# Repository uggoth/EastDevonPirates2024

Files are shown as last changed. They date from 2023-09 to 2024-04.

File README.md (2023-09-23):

# EastDevonPirates2024
Work towards Pi Wars 2024 by East Devon Pirates
Collaborating on ZyderBot, our autonomous robot entry for PiWars2024 (theme Disaster Zone)

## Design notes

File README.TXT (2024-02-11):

ZyderBot 11

Pi:   BENJI
Pico: R

Working directory is ColinThisPi
Copy new stuff into ColinBENJI then git push

startup.sh runs main program

-------------- integration ------------------------

lsusb
pico shows up as:  MicroPython Board in FS mode
ESP32 shows up as: QinHeng Electronics CH340 serial converter

ls /dev/tty*
pico shows up as:   /dev/tty/ACM0
ESP32 shows up as:  /dev/tty/USB0 (or possibly USB1)

Use Thonny on Pi for Pico. Works perfectly
Use Arduino 1.8.19 on Pi for ESP32. Compile fails, but serial monitor works
Use Arduino 2.3.0 on PC. Works perfectly (but not available for AMD architecture)

-------------- handshake test ---------------------

handshake pin on Pi is declared:
    pin_no = 18
    gpio.set_mode(pin_no, pigpio.INPUT)
    gpio.set_pull_up_down(pin_no, pigpio.PUD_UP)

handshake pin on ESP32 is declared:
    const int HANDSHAKE_PIN = 12;
    pinMode(HANDSHAKE_PIN, OUTPUT);

ESP32 sets handshake pin HIGH to signal ready to receive a command
sets LOW to indicate busy

Pi reads high pin as 1
low pi as 0
waits for 1 for 1 second, then gives up

Run  /home/pi/EastDevonPirates2024/ESP32CAMCode/HandshakeTestA/HandshakeTestA.ino on the ESP32
Run  /home/pi/ColinPiTests/test_15_A_handshake_esp32.py on the Pi
(Note: ColinPiTests is a GitHub repository to facilitate transfers)

-------------- command stream testing -------------

Run  main_test_command_stream_B_v02.py  on the Pico
Run  /home/pi/ColinThisPi/main_double_test_v01.py  on the Pi
Run  /home/pi/EastDevonPirates2024/ESP32CAMCode/CommandProtocolTestA/CommandProtocolTestA.ino on the ESP32
(Note: EastDevonPirates2024 is a GitHub repository to facilitate transfers)
Turns headlights on and off with Pico
Would turn flashlight on and off on ESP32 if it worked

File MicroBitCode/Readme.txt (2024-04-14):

Instructions for compiling to run on a Microbit.

Please note that the modulus notation for the direction needle will not 
compile on Mu Editor 1.2 on MacOS, but fine on the online python.MicroBit.org 
site and on Thonny 4.1.3 as at 20240410

compass-with-turn-indication-main.py 

Calibrates the compass by twisting in 3-axes until all the display LEDs are lit, 
then after a few seconds delay, gives a smiley on the LEDs, with a 115200 8-n-1 
output of degrees from north to the usb port, whilst using the accelerometer to 
Indicate a right or left turn on the LEDs.

Compass-needle-main.py
 
Is an extension to the above, replacing the accelerometer output with a bar 
Indicator on the LED’s pointing to North. this is a direct copy from the API documents.
 
WARNING does not compile on MU Editor v1.2 as it fails to recognise modulus symbol!

Compass-needle.hex is test code

Compass-needle-2.hex is the operational hex file to be copied to the MicroBit’s 
internal folder.

Paula Taylor East Devon Pirates 20240411

added
 
Accelerometer-only-v1-main.py

Accelerometer-only-v1.hex

Gives indication of change in direction to LEDS and printed output to serial port, no calibration needed as all output is movement relative.

Paula 20240414

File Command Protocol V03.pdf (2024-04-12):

# Command Protocol V03

We use intelligent aachments, with controllers made from Raspberry Picos, ESP32s, Arduinos etc. and communicate from the central Raspberry Pi via a serial link over USB using a command protocol. The version of this used in 2022 was very compact, but lacking in some facilies, so I have added a bit more to it, but as lile as possible.

All communicaon is iniated by the Pi. The controller cannot iniate anything. In normal use clashes are unlikely. However, to prevent clashes when the computers are busy, there is a handshake. For Pi to Pico this is a GPIO to GPIO wire. At the Pico end it is an output GPIO declared as:
machine.Pin(pin_no, machine.Pin.OUT)
At the Pi end it is an input GPIO declared as:
pigpio.set_mode(pin_no, pigpio.INPUT) pigpio.set_pull_up_down(pin_no, pigpio.PUD_UP)
If the Pico has done nothing, or the wire is disconnected, the Pi value is 1 (not 0) because of the pullup, therefore a value of 1 indicates that it is set off. Because this can be confusing the Pico has funcons set_on() and set_off(), while the Pi has is_on() which returns True or False. The controller sets the handshake to say it is ready to receive one command and unsets it while busy acng on the command. The Pi only sends commands when the Pico is ready.
The Pi has funcons:
send_command() waits a certain length of me for the handshake, if med out returns with a status code, otherwise it sends the command and waits for the feedback, which the Pico sends instantly, and then returns while the command is executed.
send_command_and_wait() is the same up to the end, where it waits aer feedback for the handshake to be set again

All communicaon is via printable characters. The command format is:
serial_no - a four character string, which gets reflected back to the Pi so the Pi can detect drop-outs if it wants to.
command - a four character command. Command sets vary according to the applicaon, but always include:
WHOU - a request for the controller to idenfy itself, in case there are mulple controllers
EXIT - an instrucon to close down
data - this is oponal and obviously applicaon dependent. If numeric it should consist of 4 digit items to be interpreted as integers.
example: 0001DRIV0050000001000000 is
serial no: 1
command: DRIV
steering: 50
throle: 0
duraon: 100 (milliseconds)
crab: 0

The controller responds immediately to every command by echoing the serial number, followed by OKOK if all is well, or some error message.
example: 0001BADCCommand not understood
Note that OKOK does not mean that the command can be executed, just that it is received and understood.

There are objects for the Pi (in ColinPiClasses) and the Pico (in ColinPicoClasses). Typical usage on the Pi would be (N.B. code not tested; it’s just a hint):
import pigpio
gpio = pigpio.pi()
import CommandStream_V05 as CommandStream
handshake = CommandStream.Handshake(4, gpio)
pico_id = 'PICOA'
my_pico = CommandStream.Pico(pico_id, gpio, handshake) serial_no_sent = 0
serial_no_sent_string = '{:04f}'.format(serial_no_sent) command = 'WHOU’
serial_no_returned, feedback, data = my_pico.send_command( serial_no_sent_string + command)
if serial_no_returned != serial_no_sent_string:
raise (ColError(’sequence error’))
serial_no_sent += 1

Typical Pico usage:
import CommandStreamPico_V05 as CommandStream
my_handshake = ThisPico.ThisHandshake()
my_stream = CommandStream.CommandStream('From Pi', my_handshake) serial_no, command, data = my_stream.get()
if command == 'WHOU':
my_stream.send(serial_no + 'OKOK' + 'PICOA')

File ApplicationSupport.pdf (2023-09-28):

# East Devon PIrates - Pi Wars 2024

The basis for our 2024 entry is the 2022 entry. This has already been tidied up with more wiring underneath, so the top is less cluttered, though you might not think so from this picture! The basic structure, with an articulated attachment platform worked well, so we are keeping it.

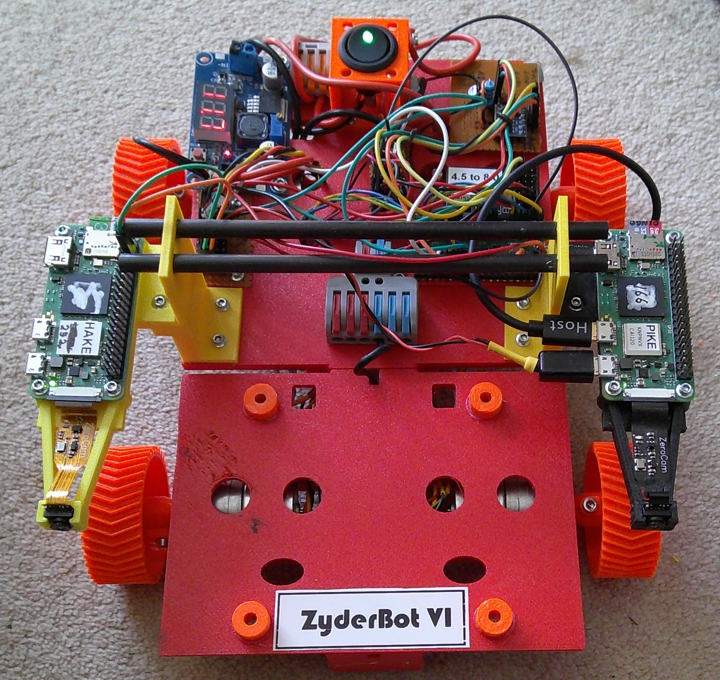
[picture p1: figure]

The robot can be remote controlled with just the Pico, so the Pi Zeros can be removed if not required (they are rather vulnerable to knocks)

The stereo Pi Zeros actually worked to some extent for the 2022 challenge, but the level of accuracy we asked of them was unobtainable. For 2024 we are just doing object identification (including line following) which is a lot simpler than SLAM, so we expect good results.

As an example of our approach, we have started work on object identification, and have created a utility for visualising colours in HSV (we are more used to RGB). This lets you play around with the OpenCV parameters in real time. In the picture I am trying to select the red crab against a complex background, with some success. Incidentally, this involves running OpenCV under the control of TKinter on a Pi Zero! You never know what’s possible until you try.

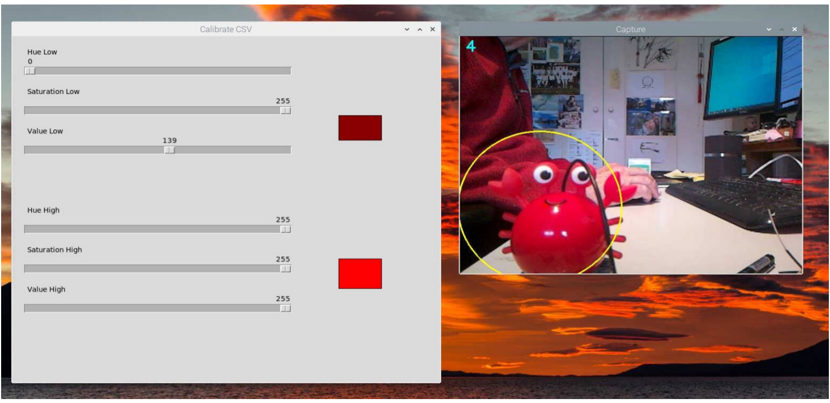
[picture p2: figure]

We have given robot demonstrations to local schools and groups (e.g. Scouts), which went down well, but have not managed to get them interested in following our Pi Wars journey. We will try again this year, and could mentor a local group if any kids nearby have entered.

We hope to have a busy and productive winter, and see you all in Cambridge

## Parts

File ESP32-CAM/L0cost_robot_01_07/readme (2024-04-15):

Consolidated version for PiWars submission

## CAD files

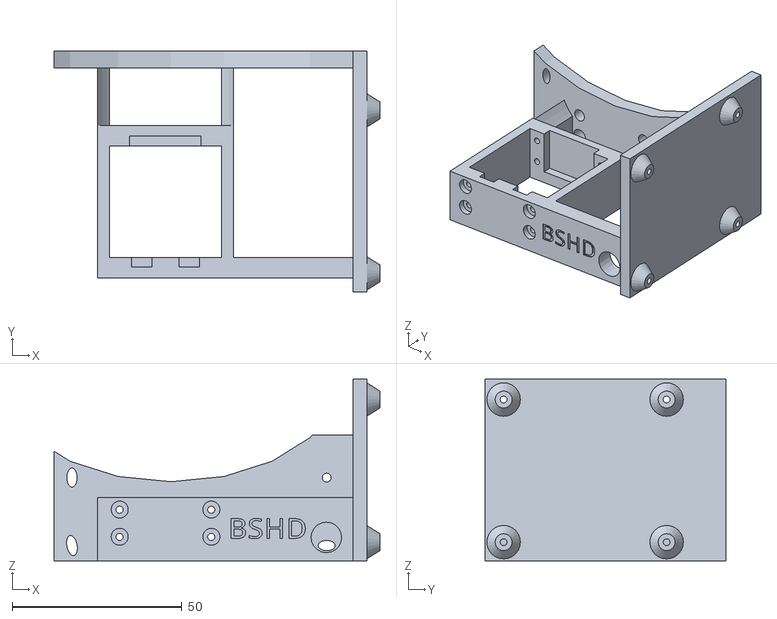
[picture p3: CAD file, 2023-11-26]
STL/ZZA Base Servo Holder D.stl
96.0 x 71.0 x 53.5

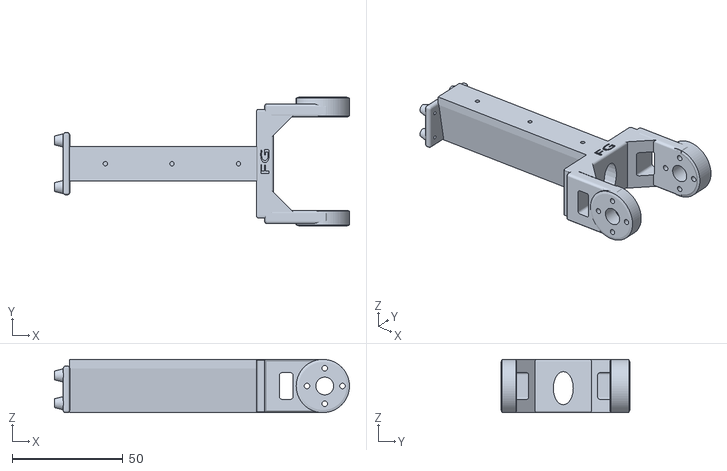
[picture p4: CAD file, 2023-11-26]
STL/ZZA Femur G.stl
132.9 x 58.0 x 24.0

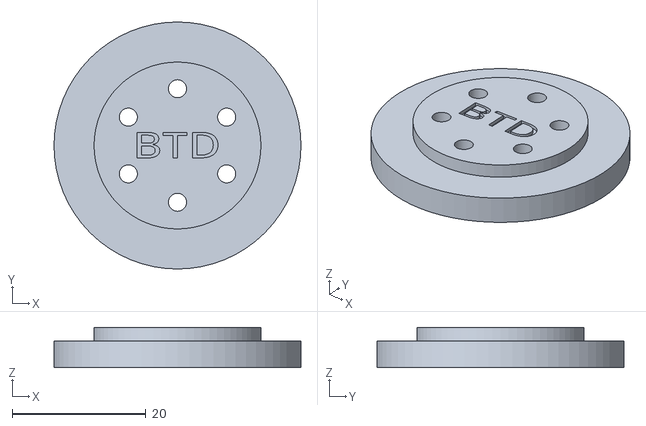
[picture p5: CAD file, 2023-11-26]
STL/ZZA Bearing Top D.stl
37.0 x 37.0 x 6.00

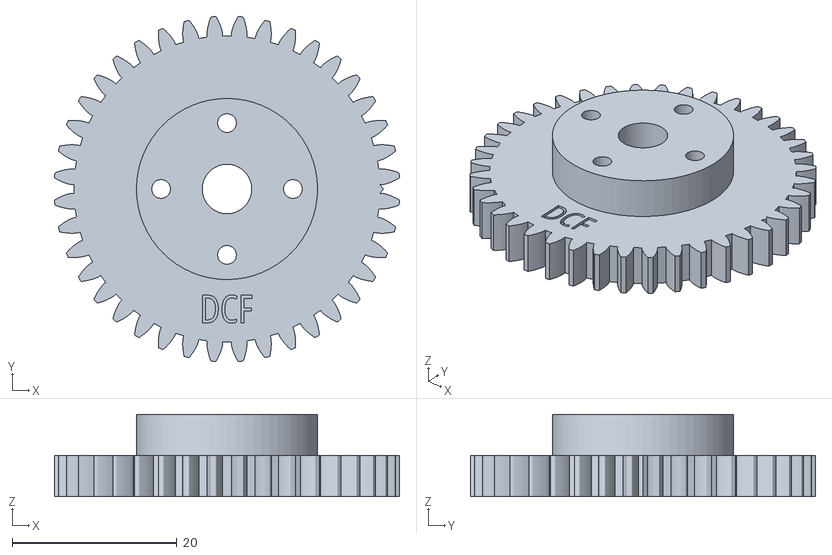
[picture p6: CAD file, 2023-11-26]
STL/ZZA Drive Cogwheel F.stl
41.9 x 41.9 x 10.0

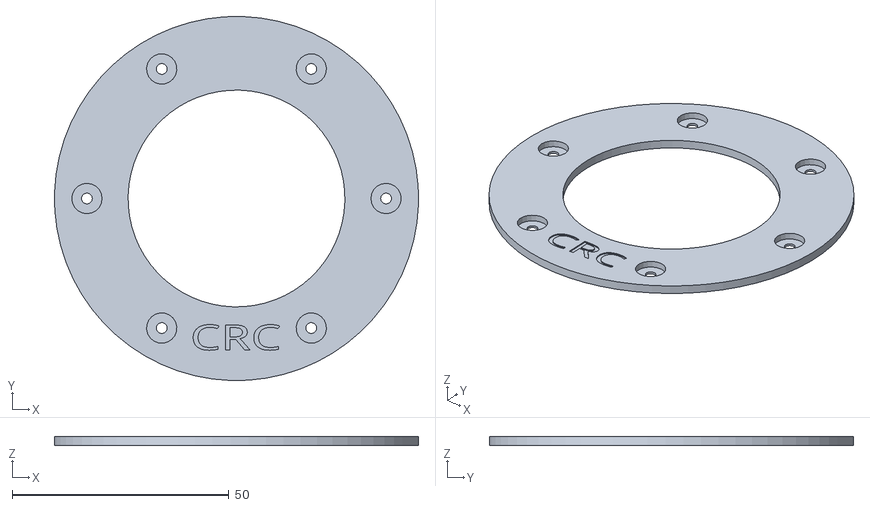
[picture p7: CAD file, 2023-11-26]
STL/ZZA Clamp Ring C.stl
84.0 x 84.0 x 2.00

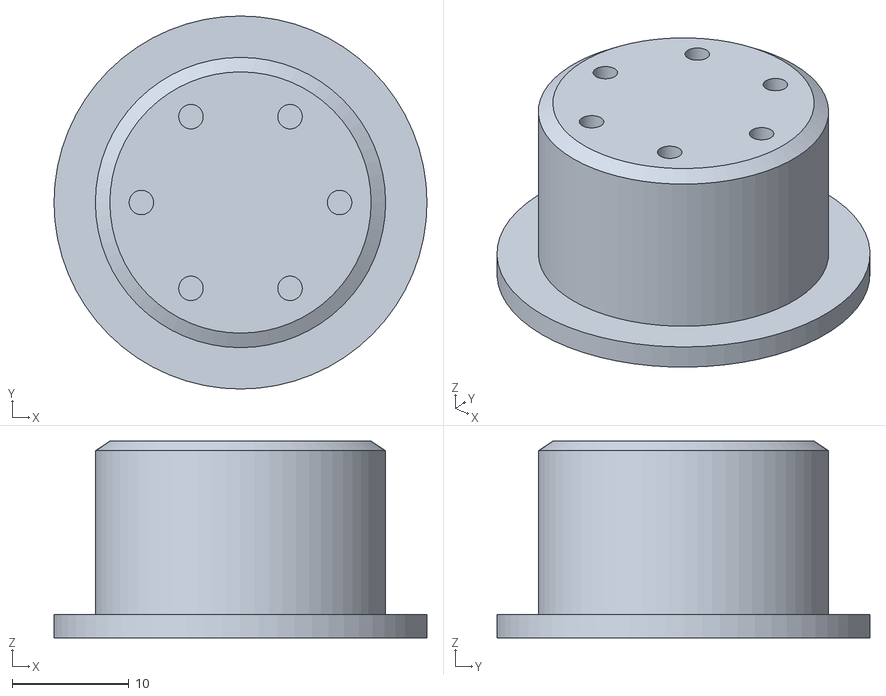
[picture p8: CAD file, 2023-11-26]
STL/ZZA Bearing Prong A.stl
32.0 x 32.0 x 16.9

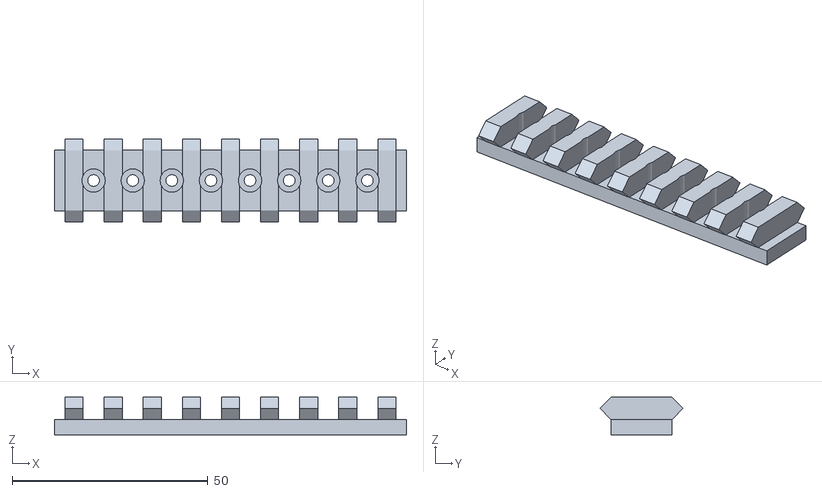
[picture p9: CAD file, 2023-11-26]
STL/ZZA Picatinny Rail C.stl
90.0 x 21.2 x 9.70

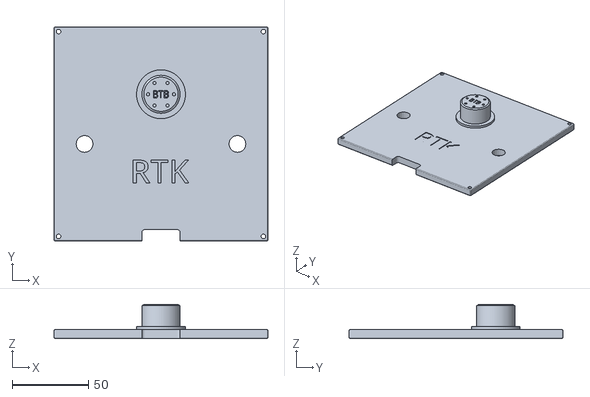
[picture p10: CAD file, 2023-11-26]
STL/ZZA Rear Top K.stl
140.0 x 140.0 x 22.3

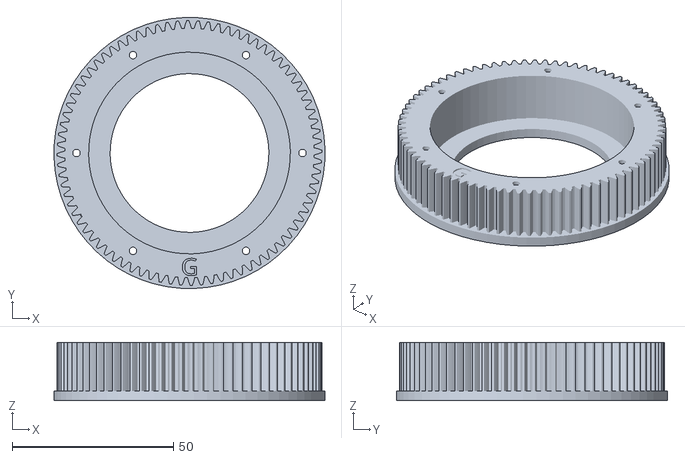
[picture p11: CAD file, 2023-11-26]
STL/ZZA Bearing Gear G.stl
84.0 x 84.0 x 18.0

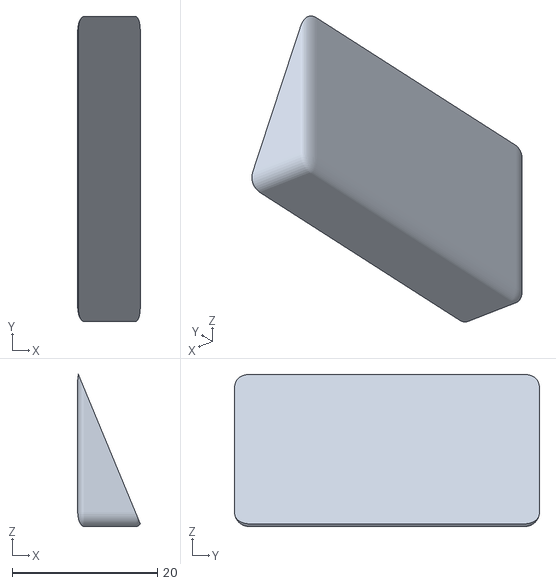
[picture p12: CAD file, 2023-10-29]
STL/ZyderBot 8 Side Window A.stl
8.62 x 42.0 x 20.9

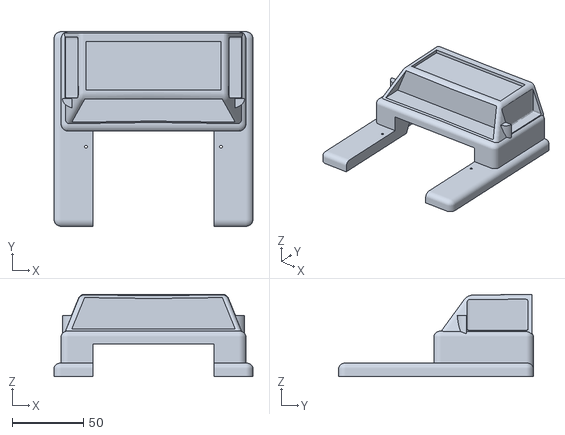
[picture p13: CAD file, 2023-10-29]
STL/ZyderBot 8 Cab G.stl
140.0 x 137.0 x 57.9

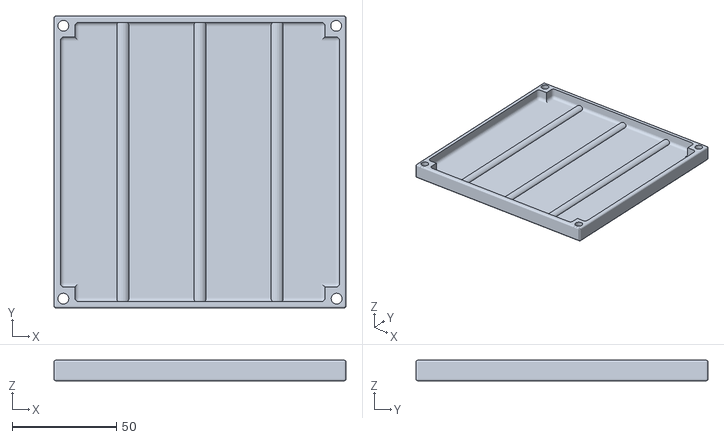
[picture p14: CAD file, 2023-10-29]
STL/ZyderBot 8 Chassis RL.stl
140.0 x 140.0 x 10.0

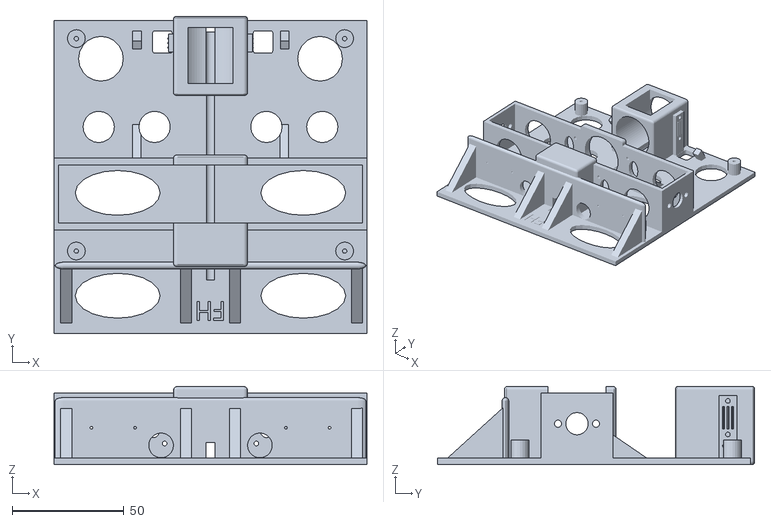
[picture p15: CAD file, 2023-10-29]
STL/ZyderBot 8 Chassis FH.stl
140.0 x 142.0 x 35.0

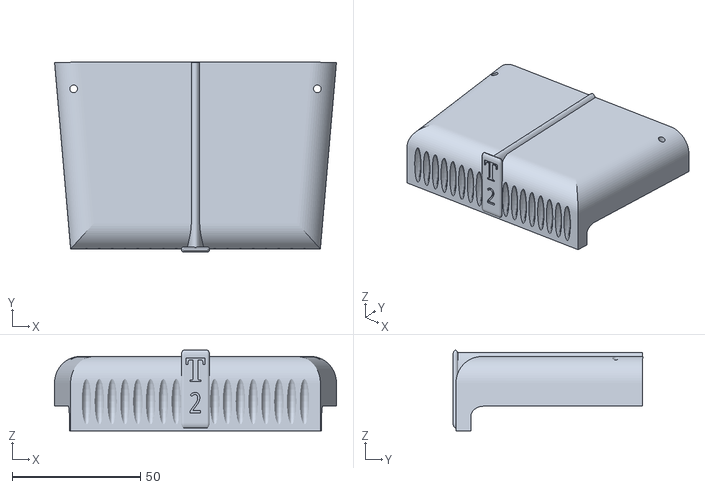
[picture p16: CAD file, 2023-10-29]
STL/ZyderBot 8 Bonnet A.stl
110.0 x 74.1 x 31.5

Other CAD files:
STL/ZyderBot 8 Front Window B.stl
STL/ZyderBot 8 Chassis RTD.stl

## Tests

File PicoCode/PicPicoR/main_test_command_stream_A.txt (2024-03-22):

Received: 0000WHOU

Sending: 0000PICOR
Received: 0001WHOU

Sending: 0001PICOR
Received: 0002HREV

Sending: 0002OKOK
Received: 0003Garbage

Sending: 0003BADC
Received: 0004HFWD

Sending: 0004OKOK
Received: 0005Garbij

Sending: 0005BADC
Received: 0006HOFF

Sending: 0006OKOK
Received: 0007EXIT

Sending: 0007OKOK
Exiting

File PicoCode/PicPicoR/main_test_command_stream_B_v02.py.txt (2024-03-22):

main_test_command_stream_B_v02.py starting

Received: 0000WHOU

Sending: 0000OKOKPICOR
Received: 0001WHOU

Sending: 0001OKOKPICOR
Received: 0006HFWD

Sending: 0006OKOK
Received: 0007HOFF

Sending: 0007OKOK
Received: 0008STOP

Sending: 0008OKOK
Received: 0000WHOU

Sending: 0000OKOKPICOR
Received: 0001WHOU

Sending: 0001OKOKPICOR
Received: 0006HFWD

Sending: 0006OKOK
Received: 0007HOFF

Sending: 0007OKOK
Received: 0008STOP

Sending: 0008OKOK
Received: 0000WHOU

Sending: 0000OKOKPICOR
Received: 0001WHOU

Sending: 0001OKOKPICOR
Received: 0006HFWD

Sending: 0006OKOK
Received: 0007HOFF

Sending: 0007OKOK
Received: 0008STOP

Sending: 0008OKOK
Received: 0000WHOU

Sending: 0000OKOKPICOR
Received: 0001WHOU

Sending: 0001OKOKPICOR
Received: 0006HFWD

Sending: 0006OKOK
Received: 0007HOFF

Sending: 0007OKOK
Received: 0008STOP

Sending: 0008OKOK
Received: 0000WHOU

Sending: 0000OKOKPICOR
Received: 0001WHOU

Sending: 0001OKOKPICOR
Received: 0006HFWD

Sending: 0006OKOK
Received: 0007HOFF

Sending: 0007OKOK
Received: 0008STOP

Sending: 0008OKOK
Received: 0000WHOU

Sending: 0000OKOKPICOR
Received: 0001WHOU

Sending: 0001OKOKPICOR
Received: 0006HFWD

Sending: 0006OKOK
Received: 0007HOFF

Sending: 0007OKOK
Received: 0008STOP

Sending: 0008OKOK
Received: 0000WHOU

Sending: 0000OKOKPICOR
Received: 0001WHOU

Sending: 0001OKOKPICOR
Received: 0006HFWD

Sending: 0006OKOK
Received: 0007HOFF

Sending: 0007OKOK
Received: 0008STOP

Sending: 0008OKOK

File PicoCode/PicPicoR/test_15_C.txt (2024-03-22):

LOOP 0
LOOP 1
LOOP 2
LOOP 3
LOOP 4
LOOP 5
LOOP 6
LOOP 7
LOOP 8

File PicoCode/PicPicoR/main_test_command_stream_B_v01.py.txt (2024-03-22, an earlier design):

main_test_command_stream_B_v01.py starting

Received: 0000WHOU

Sending: 0000PICOR
Received: 0001HREV

Sending: 0001OKOK
Received: 0002HFWD

Sending: 0002OKOK
Received: 0003HOFF

Sending: 0003OKOK
Received: 0004DRIV00500000000

Sending: 0004OKOK
spin: 0, fore_and_aft: 50, crab: 0mix a

mix b

running a
running a
running b
Received: 0005DRIV000000000000

Sending: 0005OKOK
spin: 0, fore_and_aft: 0, crab: 0mix a

running a
running a
running b
Received: 0006HOFF

Sending: 0006OKOK
Received: 0000WHOU

Sending: 0000PICOR
Received: 0001HREV

Sending: 0001OKOK
Received: 0002HFWD

Sending: 0002OKOK
Received: 0003HOFF

Sending: 0003OKOK
Received: 0004DRIV00500000000z

Sending: 0004BADC
Received: 0005DRIV000000000000

Sending: 0005OKOK
spin: 0, fore_and_aft: 0, crab: 0mix a

running a
running a
running b
Received: 0006HOFF

Sending: 0006OKOK
Received: 0000WHOU

Sending: 0000PICOR
Received: 0001HREV

Sending: 0001OKOK
Received: 0002HFWD

Sending: 0002OKOK
Received: 0003HOFF

Sending: 0003OKOK
Received: 0004DRIV005000000000

Sending: 0004OKOK
spin: 0, fore_and_aft: 50, crab: 0mix a

mix b

running a
running a
running b
Received: 0005DRIV000000000000

Sending: 0005OKOK
spin: 0, fore_and_aft: 0, crab: 0mix a

running a
running a
running b
Received: 0006EXIT

Sending: 0006OKOK
Exiting

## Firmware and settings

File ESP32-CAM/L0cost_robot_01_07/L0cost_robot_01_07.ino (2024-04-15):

/*
Version 01_07 is a checkpoint version to be used in PiWars 2024 version 01_08 will have the changes for this removed and incorporated into the 
standard command set where possible
Feature development will be frozen after this to concentrate on demonstrations and optimisation
*/
/* With debug set on, no local pin assignments and serial is assumed to be used for debug output only
All other functions continue to work
*/
/*  In the BASIC modes, pins 12 and 13 are used to provide drive signals to transistors switching current to motors
    The standard mode is to drive PNP transistors
  - if in BASICSTA mode, serial passthru on, no handshake, Wifi client, web page input, local drive commands processed to drive pins
  - if in BASICAP mode, serial passthru on, no handshake, Wifi Access Point, web page input, local drive commands processed to drive pins
  - if in BASICPS3 mode, serial passthru on, no handshake, PS3 input, local drive commands processed to drive pins
    The plus modes are to drive NPN transistors
  - if in BASICSTA+ mode, serial passthru on, no handshake, Wifi client, web page input, local drive commands processed to drive pins as positive
  - if in BASICAP+ mode, serial passthru on, no handshake, Wifi Access Point, web page input, local drive commands processed to drive pins as positive
  - if in BASICPS3+ mode, serial passthru on, no handshake, PS3 input, local drive commands processed to drive pins as positive

  - For SOKOBAN modes, drive pins are 3 and 12 (normally have reserved roles) and 13 is PWM output. This is a specialised robot role with minimal configuration
  - if in SOKOBANSTA mode, serial passthru off, no handshake, Wifi client, web page input, alternative drive pins, L293D decode
  - if in SOKOBANAP mode, serial passthru off, no handshake, Wifi Access Point, web page input, alternative drive pins, L293D decode
  - if in SOKOBANPS3 mode, serial passthru off, no handshake, PS3 input, alternative drive pins, L293D decode

  - if in REMOTESTA mode, serial passthru on, handshake on, Wifi client, web page input
  - if in REMOTEAP mode, serial passthru on, handshake on, Wifi Access Point, web page input
  - if in REMOTEPS3 mode, serial passthru on, handshake on, PS3 controller input
  
  - The SERVO modes make it easy to add a Pan and Tilt function to some of the other L0Cost robot builds
  - if in SERVOSTA mode, serial passthru on, no handshake, Wifi client, web page input, servo commands processed to pins 12 and 13
  - if in SERVOAP mode, serial passthru on, no handshake, Wifi Access Point, web page input, servo commands processed pins 12 and 13
  - if in SERVOPS3 mode, serial passthru on, no handshake, PS3 controller input, servo commands processed pins 12 and 13
  */

#include "esp_camera.h"
#include "ESPmDNS.h"
#include <WiFi.h>
#include "esp_timer.h"
#include "img_converters.h"
#include "Arduino.h"
#include "fb_gfx.h"
#include "soc/soc.h"           // disable brownout problems
#include "soc/rtc_cntl_reg.h"  // disable brownout problems
#include "esp_http_server.h"
#include "FS.h"
#include "SD_MMC.h"
#include "SPI.h"
#include <Ps3Controller.h>
#include <ESP32Servo.h>


// ===================
// Select camera model
// ===================
//#define CAMERA_MODEL_WROVER_KIT // Has PSRAM
//#define CAMERA_MODEL_ESP_EYE // Has PSRAM
//#define CAMERA_MODEL_ESP32S3_EYE // Has PSRAM
//#define CAMERA_MODEL_M5STACK_PSRAM // Has PSRAM
//#define CAMERA_MODEL_M5STACK_V2_PSRAM // M5Camera version B Has PSRAM
//#define CAMERA_MODEL_M5STACK_WIDE // Has PSRAM
#define CAMERA_MODEL_AI_THINKER  // Has PSRAM

#include "camera_pins.h"

#include "all_L0cost_robot_dcl.h"
long lastconv = 0;

// the main startup routine
void setup() {
  WRITE_PERI_REG(RTC_CNTL_BROWN_OUT_REG, 0);  //disable brownout detector

  //setCpuFrequencyMhz(240);
  // Turn off flash
  pinMode(FLASH_PIN, OUTPUT);
  digitalWrite(FLASH_PIN, LOW);
  flashState = 0;
  // setup flash LED control
  ledcSetup(flashPWMChannel, PWMFreq, PWMResolution);
  ledcAttachPin(FLASH_PIN, flashPWMChannel);
  ledcWrite(flashPWMChannel, 0);

  // initialise builtin led for status indicator
  pinMode(LED_BUILTIN, OUTPUT);
  digitalWrite(LED_BUILTIN, LOW);

  if (debugSerial || execSerial) { Serial.begin(115200); }
  if (debugSerial) { Serial.setDebugOutput(false); }

  if (debugSerial) { Serial.println("Starting...."); }
  if (debugSerial) { Serial.println(String(__FILE__) + " " + String(__DATE__) + " " + String(__TIME__)); }

  Serial.println(getCpuFrequencyMhz());

  // Writing a high output on pins 12 and 13 is done to resolve an "error" in 1-bit mode when SD_MMC.begin("/sdcard", true).
  // this may result in brief unpredictable servo or motor behaviour
  pinMode(12, OUTPUT);
  digitalWrite(12, 1);
  pinMode(13, OUTPUT);
  digitalWrite(13, 1);

  // get the sd card data
  // first setup SD card access

  setup_sdcard();

  // read SD card data to get initial configuration, wifi or ps3 data and default webpage if needed

  read_SDcard();

  // reset the pin 12 and 13 fixes
  pinMode(12, INPUT_PULLDOWN);
  pinMode(13, INPUT_PULLDOWN);


  // use camera defines to setup cammera access
  if (execVideo || execGuide) {
    camera_config_t config;
    config.ledc_channel = LEDC_CHANNEL_0;
    config.ledc_timer = LEDC_TIMER_0;
    config.pin_d0 = Y2_GPIO_NUM;
    config.pin_d1 = Y3_GPIO_NUM;
    config.pin_d2 = Y4_GPIO_NUM;
    config.pin_d3 = Y5_GPIO_NUM;
    config.pin_d4 = Y6_GPIO_NUM;
    config.pin_d5 = Y7_GPIO_NUM;
    config.pin_d6 = Y8_GPIO_NUM;
    config.pin_d7 = Y9_GPIO_NUM;
    config.pin_xclk = XCLK_GPIO_NUM;
    config.pin_pclk = PCLK_GPIO_NUM;
    config.pin_vsync = VSYNC_GPIO_NUM;
    config.pin_href = HREF_GPIO_NUM;
    config.pin_sscb_sda = SIOD_GPIO_NUM;
    config.pin_sscb_scl = SIOC_GPIO_NUM;
    config.pin_pwdn = PWDN_GPIO_NUM;
    config.pin_reset = RESET_GPIO_NUM;
    config.xclk_freq_hz = 20000000;
    config.frame_size = FRAMESIZE_SVGA;    // default for video streaming
    config.pixel_format = PIXFORMAT_JPEG;  // default for video streaming
    if (execGuide) {
      config.frame_size = FRAMESIZE_QVGA;  // default for video guidance
    }

    config.grab_mode = CAMERA_GRAB_WHEN_EMPTY;
    config.fb_location = CAMERA_FB_IN_PSRAM;
    //config.jpeg_quality = 12;
    config.jpeg_quality = 2;
    config.fb_count = 2;

    // Camera init
    esp_err_t err = esp_camera_init(&config);
    if (err != ESP_OK) {
      if (debugSerial) { Serial.printf("Camera init failed with error 0x%x \n", err); }
      execVideo = 0;
      execGuide = 0;
      errorTimer = 250;
    }
    if (execGuide) {
      sensor_t *s = esp_camera_sensor_get();
      s->set_framesize(s, (framesize_t)2);
      // s->set_special_effect(s, 2);
    }
  }

  // implememt 2 pin motor control
  if (execMotor == 1) {
    if (debugSerial) { Serial.printf("Implementing 2 pin motor control on pins %d and %d \n", rightMotorPin, leftMotorPin); }
    initPWM();
  }

  // implememt 3 pin motor control
  if (execMotor == 2) {
    if (debugSerial) { Serial.printf("Implementing 3 pin motor control with L293D on pins %d and %d \n", rightMotorPin, leftMotorPin, enableMotorPin); }
    initThreePin();
  }

  // initialise servos
  if (execServo == 1 and execMotor == 0) {
    // initialise pan/tilt servo mode
    // init servo12 and servo13
    initServos();
  }
  if (execScript) {
    // read and process startup script file
    scriptStatus = 1;
    strcpy(scriptFile, configStartup);
    while (scriptStatus) {
      fileProcessor(0);
    }
  }

  // if WiFi selected by option, process connection
  if (execWiFi) {
    // Wi-Fi connection
    //  WiFi.config(local_IP,gateway,subnet,primaryDNS,secondaryDNS);
    WiFi.setHostname(configHostname);
    // if not APT then setup a wifi client
    if (execWiFi == 1) {
      WiFi.begin(ssid, password);
      while (WiFi.status() != WL_CONNECTED) {
        delay(500);
        if (debugSerial) { Serial.print("."); }
      }
      if (debugSerial) { Serial.println(""); }
      Serial.println("WiFi connected");
    } else {  // otherwise create a wifi hot spot access point
      if (debugSerial) { Serial.println("Configuring access point..."); }
      WiFi.softAP(ssid, password);
      IPAddress myIP = WiFi.softAPIP();
      if (debugSerial) {
        Serial.print("AP IP address: ");
        Serial.println(myIP);
      }
    }

    // Start streaming web server
    startCameraServer();

    if (debugSerial) {
      Serial.print("Camera Stream Ready! Go to: http://");
      Serial.println(WiFi.localIP());
    }

    // register the hostname for use with DNS
    if (!MDNS.begin(configHostname)) {
      if (debugSerial) { Serial.println("Error starting mDNS"); }
    }
  } else if (debugSerial) {
    Serial.println("WiFi and Web page services not selected");
  }

  // PS3 setup routines
  if (execPS3) {
    Ps3.attach(notify);
    Ps3.attachOnConnect(onConnect);
    Ps3.begin(configPS3);
  }


  // Setup for processing main script file
  if (execScript) {
    scriptStatus = 1;
    strcpy(scriptFile, configMain);
  }



  //************ end of setup
}

// the loop function flashes the internal LED on and off when connected to Wifi and
// schedules the reading of command files
void loop() {

  if (debugSerial) {
    // delay(10);  // delay to slow/stop race contitions in testing
  }

  long startconv = 0;
  long endconv = 0;
  long enddetect = 0;
  long endoverlay = 0;
  long endloop = 0;
  long convgap = 0;
  loopTimer = millis();  // all functions on each iteration of the loop use this value

  // display Wifi is active via flashing LED
  if (execWiFi) {
    // wifi indicator LED
    if (WiFi.status() == WL_CONNECTED) {
      if (ledTimer <= loopTimer) {
        ledTimer = loopTimer + errorTimer * 2;
        digitalWrite(LED_BUILTIN, HIGH);
      }
      if (ledTimer - errorTimer <= loopTimer) {
        digitalWrite(LED_BUILTIN, LOW);
      }
    } else {
      digitalWrite(LED_BUILTIN, LOW);
    }
  }

  // switch off flash led if time expired
  if (flashTimer < loopTimer) {
    cmdProcessor("LFLASHOFF", 0);
    flashTimer = FLASH_ON_TIME;
  }

  // check for and process serial input
  // this is run continuously until serial processing is complete or an exception occurs
  // out of input data, excessive input data and function not active are exceptions
  while (!serialProcessor(0)) {};

  // process script file if active
  fileProcessor(1);

  // take script out of pause if timer expired
  if (scriptProcess == 3) {
    //if scriptTimer has expired, set script to process next command
    if (scriptTimer <= loopTimer) {
      if (debugSerial) { Serial.println("Script pause ended"); }
      scriptProcess = 2;
    }
  }

  // check if motor command has expired
  // if so, stop robot
  if (execMotor && execPWM) {
    if (motorTimer <= loopTimer) {
      if (execMotor == 1) {
        ledcWrite(rightMotorPWMSpeedChannel, 0);
        ledcWrite(leftMotorPWMSpeedChannel, 0);
      } else if (execMotor == 2) {
        ledcWrite(enableMotorPWMSpeedChannel, 0);
      }
    }
  }

  // Video processing routines
  // any incuded print statements are for development testing and will be removed in a later version
  if (execGuide) {
    // only execute this section if automatic video guidance in use
    if (!frameAvailable) {
      //     Serial.printf("Start conv: %d \n", millis());
      // get frame into working frame buffer
      startconv = millis();
      convgap = lastconv - startconv;
      lastconv = startconv;
      videoProcessing();
      endconv = millis();
      //    Serial.printf("End conv: %d \n", millis());
    }

    // if frame available, process selected detection routines
    if (frameAvailable == 1) {
      // call line detection processing. This is currently only setup for white line on black background
      // three frame positions are provided here, top, centre and bottom, and three 'lines' can detected and reported on in each
      // the position of top, centre and bottom can be defined in commands to suit the camera
      // by default, only the centre position is updated, selecting BOTTOM updates both centre and bottom, and selecting
      // TOP updates top, centre and bottom
      
      if (execMask) {
        writeMask(maskColour);
      }
      if (execLine) {
        // // for black processing, invert frame
        // if (colourDetect == 0) {
        //   pixelInvert();
        // }
        switch (execLineProcessing) {
          case 1:
            findLineTop(colourDetect);
          case 2:
            findLineBottom(colourDetect);
          default:
            findLineCentre(colourDetect);
        }
      }
      // call blob detection processing
      // the initial reporting is targeted on the centre of the largest blob detected
      else if (execBlob) {
        long videoTime = millis();
        switch (execBlobProcessing) {
          case 0:
            // standard blob processing, updates blob location variables
            findBlob(colourDetect);
            break;
          case 1:
            // paints a heatmap of colour for video guidance tuning
            heatMap(colourDetect, 1);
            break;
          case 2:
            // paints a colour intensity map  for video guidance tuning
            scanTest(colourDetect);
            break;
          case 3:
            // paints a colour detection map for video guidance tuning
            findColours();
            break;
          default:
            findBlob(colourDetect);
            break;
        }
        // if (debugSerial) { Serial.printf("%d \n", millis() - videoTime); }
      }

      enddetect = millis();

      // end of successful processing, set frame available for processing elsewhere
      // or flag frame processing complete and free frame buffer

      if (execVideo) {
        switch (execOverlay) {
          case 1:
            crossHairs(BLUE);
            break;
          case 2:
            graduations(BLUE);
            break;
          case 3:
            percentGrads(BLUE);
            break;
        }
        frameAvailable = 5;
      } else {
        frameAvailable = 0;
        if (guideFrame.data) {
          free(guideFrame.data);
          guideFrame.data = NULL;
        }
        // free(guideFrame.data);
        //guideFrame.data = NULL;
      }
    }
  }
  endoverlay = millis();
  // execute demo functions if selected
  if (execDemo) {
    if (execFollower) {
      // call line follower demo routine
      lineFollower();
    } else if (execBlobFollower) {
      // call bllob follower routine
      blobFollower();
    } else if (execTargetFollower) {
      // call target follower routine
      targetFollower();
    } else execDemo = 0;
  }
  endloop = millis();
  if (startconv) {
    if (debugSerial) {Serial.printf("Start loop = %d, Conversion = %d Detect = %d, Overlay = %d, Loop = %d  Interval = %d\n", loopTimer, endconv - startconv, enddetect - endconv, endoverlay - enddetect, endloop - loopTimer, convgap); }
  }
  // end of loop routine
}

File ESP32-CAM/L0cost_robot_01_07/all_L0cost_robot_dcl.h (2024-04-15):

// the following are code prototypes ++++++++++++++++++++++++++++
int setup_sdcard(void);
void read_SDcard(void);
void fileParse(char *line, int fileType, int lineNo);
int read_datafile(fs::FS &fs, const char *path, int fileType);
int readHtml(fs::FS &fs, const char *htmlf);

// flagset routines
void flagSet(char execType[20]);
void flagReport(void);

// robothandler routines
int cmdProcessor(char variable[], int source);
int sendHandshake(char commsString[]);
int remoteProcessor(char commsString[]);
int localProcessor(char localVariable[], int source);
void initPWM();
int motorControl(char localVariable[], int source);
int shiftLeft(char variable[], int step);
int initServos(void);
int servoControl(char localVariable[]);
void fileProcessor(int type);
int serialProcessor(int type);
int getValue(char fullCommand[], int offset);
int cmdCmp(char fullCommand[], char testCommand[]);
int cameraControl(char localVariable[]);
int guideControl(char localVariable[]);
void shiftFileName(char *fileName);
void detachPWM(void);
void attachPWM(void);
void initThreePin(void);
int ps3Processor(char ps3Command[], int source);
int htmlProcessor(char htmlCommand[], int source);
int lockSet(int &lock, int value);
int lockUnSet(int &lock, int value);
int lockTest(int &lock, int value);
void picoPinOn();
void picoPinOff();

// video handling routines
int videoProcessing(void);
int setVideoMode();
int setGuideMode();
long findLineCentre(long colour);
long findLineTop(long colour);
long findLineBottom(long colour);
long findLine(long lineInstances[13], long colour, long startLine, long startCol, long endCol, long threshold, long adjacent, long column, long update);
long findBlobInstances(long colour);  // call findBlob routine
long findBlob(int colour);
int scanBlob(int pixLine, int pixCol);
int scanTest(long colour);
int setPixel(long location, int colour);
long heatMap(long colour, int background);
long findSquare(long colour);
long findColours(void);
int crossHairs(long colour);
int graduations(long colour);
int percentGrads(long colour);
long detectColour(long pixel, int colour);
int pixelLuminance(void);
int procGuidance(int type);
long pixelInvert(void);
long pixelPreprocess(int type1, int type2, int type3);
int writeMask(int colour);

// PS3 routines
void onConnect();
void notify();

// demo functions
int demoControl(char localVariable[]);
int lineFollower(void);
int blobFollower(void);
int targetFollower(void);

// html routines
static esp_err_t index_handler(httpd_req_t *req);
static esp_err_t stream_handler(httpd_req_t *req);
static esp_err_t cmd_handler(httpd_req_t *req);
static esp_err_t data_handler(httpd_req_t *req);
void startCameraServer();

//++++++++++++++++++++++++++++++++++++++++++++++++++++++++++++++++

#define WIFI 1
#define CMDFILE 2
#define CONFIG 3
#define PS3CONFIG 4


#define FLASH_PIN 4
#define LED_BUILTIN 33

// demo function variables
int factorP = 1;    // Proportional PID factor. This is to be interpreted as a 2.2 decimal number
int factorI = 0;    // Integral PID factor. This is to be interpreted as a 2.2 decimal number
int factorD = 0;    // Derivative PID factor. This is to be interpreted as a 2.2 decimal number

// debug variables
int webSwitch = 1;


// execution flags
int execWiFi = 0;            // use wifi, value indicates 0= no wifi, 1=client or 2=access point
int execPS3 = 0;             // use PS3 input
int execSensor = 0;          // use serial pins for local sensor input
int execSerial = 1;          // configure and pass output to serial port
int execMotor = 0;           // configure motor control output
int execHandshake = 0;       // pins configured for remote controller serial handshake
int execServo = 0;           // configure servo control output, valu indicates either 2 or 4 pins
int execPWM = 0;             // motor control attached
int execPolarity = 0;        // motor polarity, 0 = negative, 1 = positive
int execVideo = 1;           // activate video streaming
int execGuide = 0;           // activate video guidance
int execScript = 1;          // activate script processing
int execLine = 0;            // activate line following video processing
int execLineProcessing = 0;  // type of line processing to carry out 0 = centre, 1 = centre and bottom, 2 = top, centre and bottom
int execBlob = 0;            // activate blob following video processing
int execBlobProcessing = 0;  // activate type of blob processing, 0 = standard
int execOverlay = 0;         // add overlay to guide video display
int execPico = 0;            // activates bidirectional serial protocal with Raspberry Pi Pico
int execMask = 0;            // masks out a portion of the image (all values set to black)

int execDemo = 0;           // set if demo activity selected
int execFollower = 0;       // set if line follower demonstration used
int execBlobFollower = 0;   // set if blob follower demonstration used
int execTargetFollower = 0; // set if blob tracker demonstration used

// demo processing
int demoStatus = 0;         // maintains demo status 0 = no action, 1 = calibrate, 2 = follow


// pico processing section
char sequenceNumber[5] = "    ";  // pico sends a sequence number which must be returned as header to response
int picoPin = 13;                 // hardware handshake pin


// script file processing
char scriptFile[20] = "/startup.txt";       // default script name
int scriptStatus = 0;                      // maintains status of current script execution
int scriptProcess = 0;                      // tracks current script process
char scriptBuf[200];                        // buffer for script processing
File script;                                // file definition for script processing

// timer counters
long loopTimer = 0;     // main timer variable for loop
long ledTimer = 0;
long runTimer = 0;
long scriptTimer = 0;
int errorTimer = 500;   // led flash delay 500ms is for wifi connected ok, 250ms of for camera not working

// timers for motor control
long motorTimer = 0;          // timeout for last motor command
long directTimer = 0;         // timeout for direct control
long defaultTimeOut = 30000;  // default set to 30 seconds
long directTimeOut = 30000;

// flash led timer definitions
#define FLASH_ON_TIME 99999999  // flash LED timer set to 10,000 seconds, could be more but just sets a practical limit
#define FLASH_PEEK_TIME 5000
long flashTimer = FLASH_ON_TIME;
int flashIntensity = 128;  // default PWM value for flash LED when illuminated
const int flashPWMChannel = 7;

// configuration defaults and variables
char *htmlPage;
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

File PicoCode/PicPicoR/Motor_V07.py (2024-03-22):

module_name = 'Motor_V07.py'
module_description = 'General definition of all motors. Modified 28/Jan/2024'

if __name__ == "__main__":
    print (module_name, 'starting')

import GPIOPico_V30 as GPIO
ColObjects = GPIO.ColObjects
import utime
import machine

class FIT0441BasicMotor(ColObjects.Motor):  #  cut down for R/C
    def __init__(self, name, direction_pin_no, speed_pin_no):
        super().__init__(name)
        self.direction_pin_GPIO = GPIO.GPIO(pin_no=direction_pin_no, type_code='MOTOR', name=name+'_direction_'+str(direction_pin_no))
        self.direction_pin = machine.Pin(direction_pin_no, machine.Pin.OUT)
        self.speed_pin_GPIO = GPIO.GPIO(pin_no=speed_pin_no, type_code='MOTOR', name=name+'_speed_'+str(speed_pin_no))
        self.speed_pin = machine.PWM(machine.Pin(speed_pin_no))
        self.speed_pin.freq(25000)
        self.duty = 0
        self.stop_duty = 65534
        self.min_speed_duty = 65000
        self.max_speed_duty = 0
        self.clockwise = 1
        self.anticlockwise = 0

    def __str__(self):
        outstring = self.name
        outstring += ', speed pin: ' + str(self.speed_pin_GPIO.pin_no)
        outstring += ', direction pin: ' + str(self.direction_pin_GPIO.pin_no)
        return outstring

    def clk(self, speed):  #  speed is from 0 to 100
        self.direction_pin.value(self.clockwise)
        self.set_speed(speed)

    def anti(self, speed):
        self.direction_pin.value(self.anticlockwise)
        self.set_speed(speed)

    def run(self, speed):  #  speed is from -100 to +100
        if speed == 0:
            self.stop()
            return
        if speed > 0:
            self.clk(speed)
        else:
            self.anti(-speed)

    def stop(self):
        duty = self.stop_duty
        self.speed_pin.duty_u16(duty)
        utime.sleep_ms(1)
        
    def close(self):
        self.direction_pin_GPIO.close()
        self.speed_pin_GPIO.close()
        super().close()

    def set_speed(self, speed):  #  as a percentage
        self.duty = (self.min_speed_duty
                     - int(float(self.min_speed_duty - self.max_speed_duty)
                        * (float(speed) / 100.0)))
        self.speed_pin.duty_u16(self.duty)
    
    def set_direction(self, direction):  # 1 = clockwise, 0 = anticlockwise
        if direction == 1:
            self.direction_pin.value(self.clockwise)
        elif direction == 0:
            self.direction_pin.value(self.anticlockwise)

class FIT0441Motor(ColObjects.Motor):
    def __init__(self, name, direction_pin_no, speed_pin_no, pulse_pin_no=None):
        super().__init__(name)
        self.direction_pin_GPIO = GPIO.GPIO(pin_no=direction_pin_no, type_code='MOTOR', name=name+'_direction_'+str(direction_pin_no))
        self.direction_pin = machine.Pin(direction_pin_no, machine.Pin.OUT)
        self.speed_pin_GPIO = GPIO.GPIO(pin_no=speed_pin_no, type_code='MOTOR', name=name+'_speed_'+str(speed_pin_no))
        self.speed_pin = machine.PWM(machine.Pin(speed_pin_no))
        self.duty = 0
        self.stop_duty = 65534
        self.min_speed_duty = 65000
        self.max_speed_duty = 0
        self.clockwise = 1
        self.anticlockwise = 0

    def __str__(self):
        outstring = self.name
        outstring += ', speed pin: ' + str(self.speed_pin_GPIO.pin_no)
        outstring += ', direction pin: ' + str(self.direction_pin_GPIO.pin_no)
        return outstring

    def clk(self, speed):
        self.direction_pin.value(self.clockwise)
        self.set_speed(speed)

    def anti(self, speed):
        self.direction_pin.value(self.anticlockwise)
        self.set_speed(speed)

    def deinit(self):
        self.speed_pin.deinit()

    def stop(self):
        duty = self.stop_duty
        self.speed_pin.duty_u16(duty)
        utime.sleep_ms(1)
        
    def close(self):
        self.deinit()
        utime.sleep_ms(5)
        self.direction_pin_GPIO.close()
        self.speed_pin_GPIO.close()
        super().close()

    def set_speed(self, speed):  #  as a percentage
        self.duty = (self.min_speed_duty
                     - int(float(self.min_speed_duty - self.max_speed_duty)
                        * (float(speed) / 100.0)))
        self.speed_pin.duty_u16(self.duty)
    
    def set_direction(self, direction):  # 1 = clockwise, 0 = anticlockwise
        if direction == 1:
            self.direction_pin.value(self.clockwise)
        elif direction == 0:
            self.direction_pin.value(self.anticlockwise)

class FIT0441MotorWithPulses(ColObjects.Motor):
    def __init__(self, name, direction_pin_no, speed_pin_no, pulse_pin_no):
        super().__init__(name)
        self.direction_pin_GPIO = GPIO.GPIO(pin_no=direction_pin_no, type_code='MOTOR', name=name+'_direction_'+str(direction_pin_no))
        self.direction_pin = machine.Pin(direction_pin_no, machine.Pin.OUT)
        self.speed_pin_GPIO = GPIO.GPIO(pin_no=speed_pin_no, type_code='MOTOR', name=name+'_speed_'+str(speed_pin_no))
        self.speed_pin = machine.PWM(machine.Pin(speed_pin_no))
        self.pulse_pin_GPIO = GPIO.GPIO(pin_no=pulse_pin_no, type_code='MOTOR', name=name+'_pulse_'+str(pulse_pin_no))
        self.pulse_pin = machine.Pin(pulse_pin_no, machine.Pin.IN, machine.Pin.PULL_UP)
        self.pulse_pin.irq(self.pulse_detected, machine.Pin.IRQ_FALLING)
        self.pulse_count = 0
        self.pulse_checkpoint = 0
        self.pulse_endpoint = 0
        self.duty = 0
        self.stop_duty = 65534
        self.min_speed_duty = 65000
        self.max_speed_duty = 0
        self.clockwise = 1
        self.anticlockwise = 0

    def __str__(self):
        outstring = self.name
        outstring += ', speed pin: ' + str(self.speed_pin_GPIO.pin_no)
        outstring += ', direction pin: ' + str(self.direction_pin_GPIO.pin_no)
        outstring += ', pulse pin: ' + str(self.pulse_pin_GPIO.pin_no)
        return outstring

    def clk(self, speed):
        self.direction_pin.value(self.clockwise)
        self.set_speed(speed)

    def anti(self, speed):
        self.direction_pin.value(self.anticlockwise)
        self.set_speed(speed)

    def pulse_detected(self, sender):
        self.pulse_count += 1
        if self.pulse_endpoint > 0:
            if self.pulse_count >= self.pulse_endpoint:
                self.stop()

    def get_pulses(self):
        return self.pulse_count

    def deinit(self):
        self.pulse_pin.irq(None)
        self.speed_pin.deinit()

    def stop(self):
        duty = self.stop_duty
        self.speed_pin.duty_u16(duty)
        utime.sleep_ms(1)
        
    def close(self):
        self.deinit()
        utime.sleep_ms(5)
        self.direction_pin_GPIO.close()
        self.speed_pin_GPIO.close()
        self.pulse_pin_GPIO.close()
        super().close()
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

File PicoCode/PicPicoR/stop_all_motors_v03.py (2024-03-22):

module_name = 'stop_all_motors_v03.py'
print (module_name)

from machine import Pin, PWM
import utime

lf_speed_pin = PWM(Pin(2))
rf_speed_pin = PWM(Pin(6))
lb_speed_pin = PWM(Pin(10))
rb_speed_pin = PWM(Pin(21))

lf_speed_pin.freq(25000)
rf_speed_pin.freq(25000)
lb_speed_pin.freq(25000)
rb_speed_pin.freq(25000)

stop_duty = 65535

lf_speed_pin.duty_u16(stop_duty)
rf_speed_pin.duty_u16(stop_duty)
lb_speed_pin.duty_u16(stop_duty)
rb_speed_pin.duty_u16(stop_duty)

utime.sleep(0.2)

lf_speed_pin.deinit()
rf_speed_pin.deinit()
lb_speed_pin.deinit()
rb_speed_pin.deinit()

led = Pin('LED', Pin.OUT)

for i in range(10):
    led.toggle()
    utime.sleep(0.15)
    
print (module_name, 'finished')

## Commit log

2023-08-31 Create test_22_hsv_calibrate_B_v06.py
    Utility for calibrating HSV parameters
2023-10-29 Added 3D designs to repository
    Was TONKER 4, now, with some changes ZyderBot 8
    [ZyderBot 8 Bonnet A.stl, ZyderBot 8 Cab G.stl, ZyderBot 8 Chassis FH.stl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]
2023-11-26 Zombie Arm STLs
    Version with detachable Picatinny rail
    [ZZA Base Servo Holder D.stl, ZZA Bearing Gear G.stl, ZZA Bearing Prong A.stl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]
2023-11-26 Raspberry Pi Code from DIVA
    posing_setup_small.py allows you to pose the zombie arm in different positions to check range of movement etc.
2023-11-26 Pico Code
    Basic remote control stuff
2024-04-11 Create DIP Switches.txt
2024-04-12 pico main 20
2024-04-16 External Light Callback and target presentation
    External Light Callback added. See #Add to Main Code section
    Bright Target presentation tidy and count added in main code for and example
    [zombies.csv]
